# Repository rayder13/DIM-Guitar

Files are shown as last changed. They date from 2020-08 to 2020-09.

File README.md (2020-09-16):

# DIM-Guitar

## Introduction

(Did It Myself)DIM Guitar is a DIY full replacement for the oem electronics in a Warriors of Rock Playstation/Xbox Guitar Hero guitar. The result is a wired Clone Hero compatible guitar (Not console compatible), allowing you to either refurbish an existing guitar (WoR only atm) or create your own guitar from scratch. I will possibly be adding custom Fret key files, other 3d printable mounting options (For control board etc) and maybe new body variations that work with the original WoR (Warriors of Rock) body.

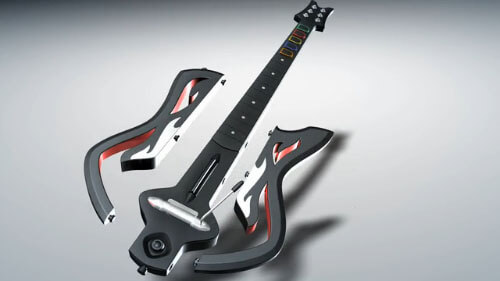
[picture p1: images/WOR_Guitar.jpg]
Image of WoR Guitar


## Progress

Electronics [Progress](PROGRESS.md) to keep up to date on how the project is going.

3D Print file [Progress](PRINTED.md).

Quick and dirty [Update Log](UPDATES.md).

## License

While I will be selling component kits and complete ready to install kits, the entire project is being released under GPL 3.0. Please read the license if you have any questions as to what you can and can't do.

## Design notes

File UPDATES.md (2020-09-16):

# Update Log

## 16/09/20

- Initial commit for 3D print files. WoR Fret Button added.

## 15/09/20

- Initial Arduino code commit to github.

## 16/08/20

- All pcb headers updated to carry 5v for future upgrades (led's etc).
- Update log added.
- Updated github files to 0.2.

## 11/08/20

- Initial commit of version 0.1.

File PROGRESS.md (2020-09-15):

# Progress

## Pinout

Below is the proposed pinout for the DIM Guitar based on an Arduino Pro Micro. The board should have enough GPIO's to accommodate the project. Hoping to use the TX/RX pins for future features but we will see how that pans out. Pin 7 is designated Fret 6 for future proofing a fork into GH6 6 fret guitar retro fit.

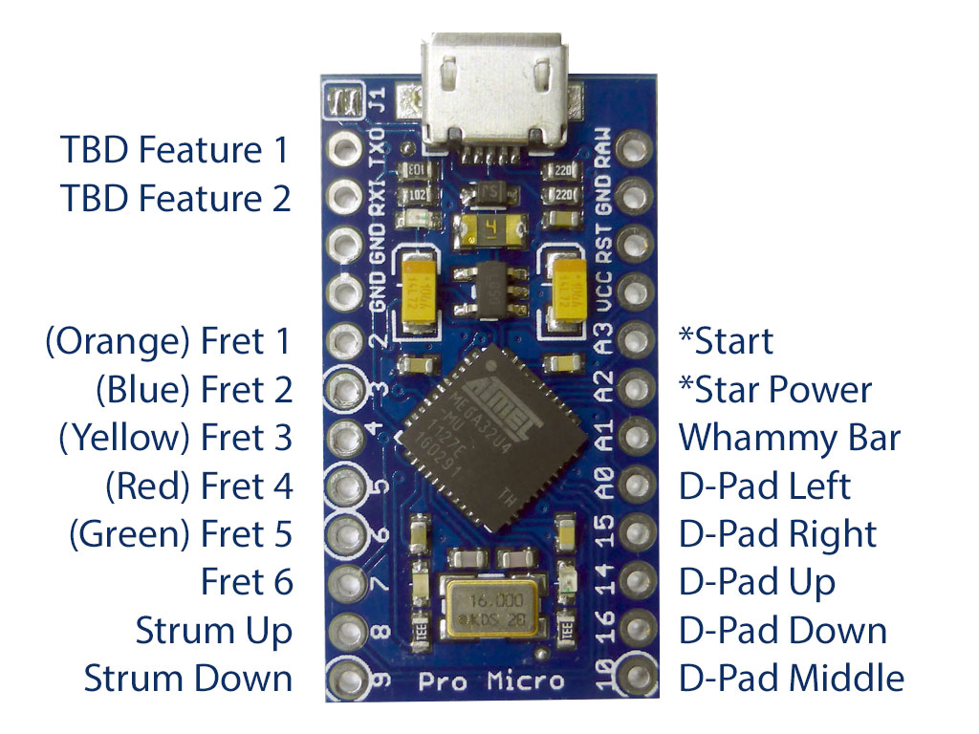
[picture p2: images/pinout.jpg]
Image of Pro Micro Pinout


## Working Prototype

Working prototype with D-Pad and Fretboard hooked up.

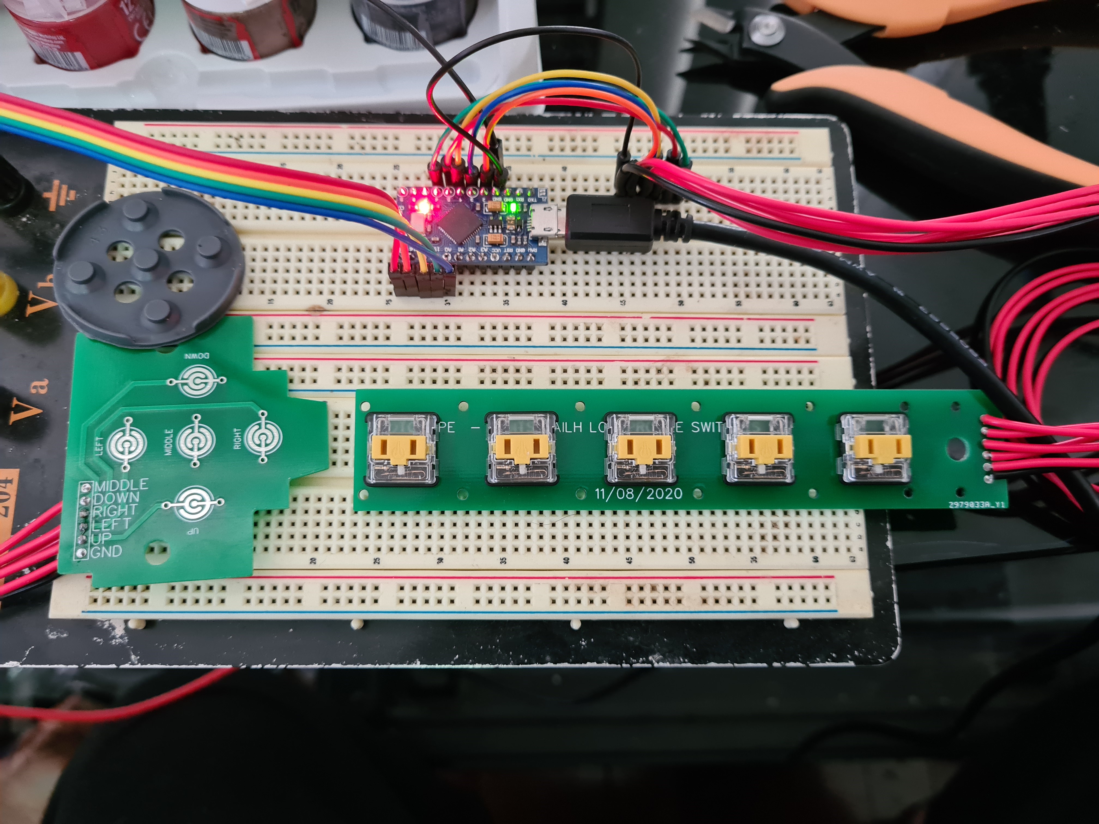
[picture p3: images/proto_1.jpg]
Image of current prototype


## Fretboard

- **September 15th 2020** Kailh switches arived today. Had to order a second lot directly from Kailh as the switches I originally ordered nearly 8 weeks ago from a reseller still haven't arrived. Turns out my pcb footprint for the switches is flipped horizontally. Not a huge deal as i can just flip the pcb given the only components are switches and the pcb is symmetrical vertically. Plus there are additions to come for the pcb so as long as i have a working prototype i can still progress.
- The switches appear to be too tall even though they are pretty much the shortest i could find. There isn't enough room below the pcb to mount them in the pcb so the fret buttons will have to be modified to get the extra internal travel needed.

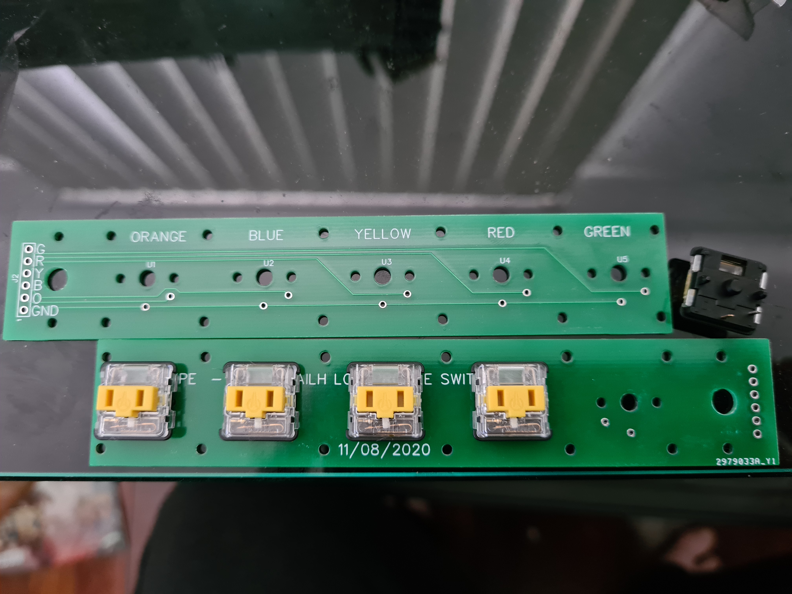
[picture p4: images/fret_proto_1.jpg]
Image of Prototype fretboard pcb


- **August 20th 2020** PCB's arrived 4 days early. Happy with these as far as quality and accuracy goes.

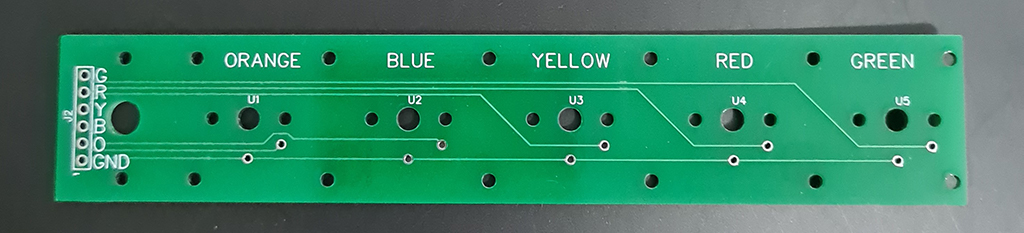
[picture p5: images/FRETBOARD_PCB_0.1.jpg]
Image of Prototype fretboard pcb


- Prototype pcb done and ordered. The pcb will use Kailh Choc low profile switches instead of the oem rubber membrane keys. This should fix sloppy fret keys and allow for a better feel depending on your preferences with tactile, clicky and linear keys available in the low profile switches.
- Potential to add led's to each switch for either all on lighting while connected or having the fret light up when pressed.

## D-Pad

- **August 20th 2020** PCB's arrived 4 days early.
- Works way better than expected, though research says that the exposed copper contacts will likely corrode over time and become unreliable. Will have to look into carbon or ENIG as a better option. For now the prototype 100% works as expected with no problems.

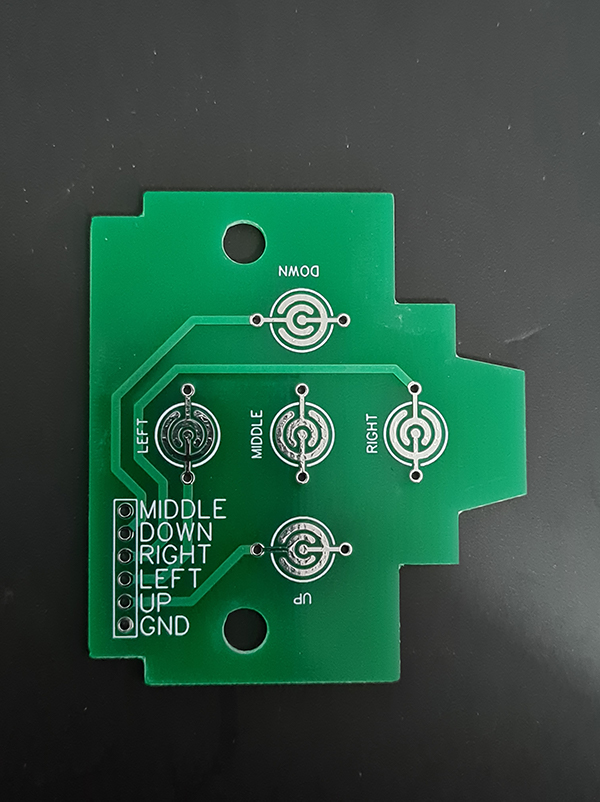
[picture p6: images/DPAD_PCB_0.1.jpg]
Image of Prototype dpad pcb


- Prototype pcb done and ordered. Utilising the original rubber membrane pad given how little the keys get used.
- Swapping to mechanical keys might not be easy given the confinement of space.

## Strummer

- **September 15th 2020** Kailh switches turned up. I ordered a set of Kailh box dark yellow switches to test for the strummer. They have a cherry footprint but a much thicker stem than normal Cherry switches which i like. Using the same footprint however gives you the ability to chop and change between switches as desired. They are however around 1-2mm shorter than the OEM switches. Might need a hat to make sure the strum bar doesn't feel "loose".

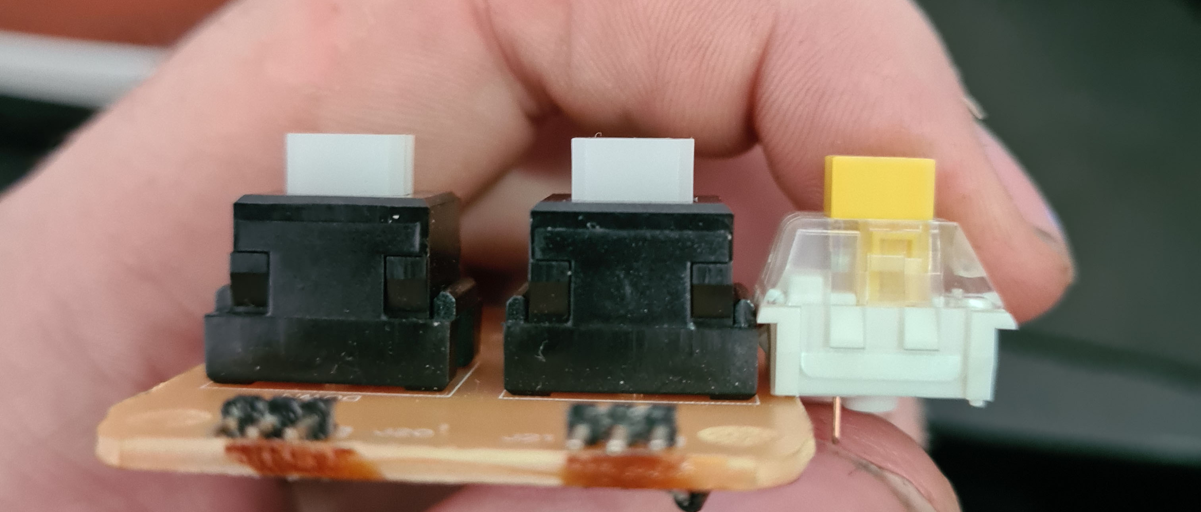
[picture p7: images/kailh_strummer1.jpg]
Image of Kailh box switch compared to OEM


- Prototype pcb in progress. Cherry MX Black version design done but i am waiting for the Kailh Chic low profile switches to show up to decide whether to use them, MX Cherry blacks or Alps keys.

Image of Prototype Strummer pcb

## Start/Star Power/Whammy

- Prototype pcb in progress. Will likely use Kailh Choc low profile switches as well.

Image of Prototype Mid Board pcb

## Arduino Controller

- Full working prototype was made on an Arduino Leonardo board. ~~Custom board based on the ATMEGA34U2 mcu will be prototyped after all of the other pcb's are verified working as intended.~~ A full pin hookup guild will be added on full release for anyone who wants to use an existing ATMEGA34U2 board (Arduino pro micro etc) as main controller board.
- After a bit of consideration the controller board will be a carrier board for an Arduino Pro Micro footprint instead of a custom 34U2 board. This will keep the costs down and realistically for this project there's no point reinventing the wheel.

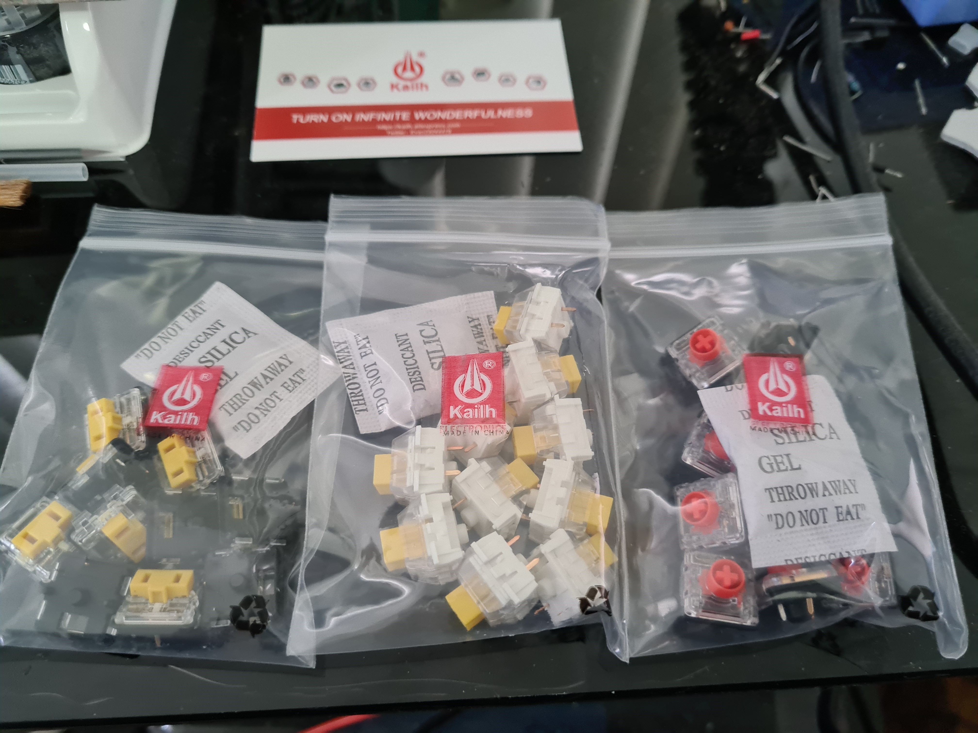
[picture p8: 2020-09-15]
images/switches.jpg

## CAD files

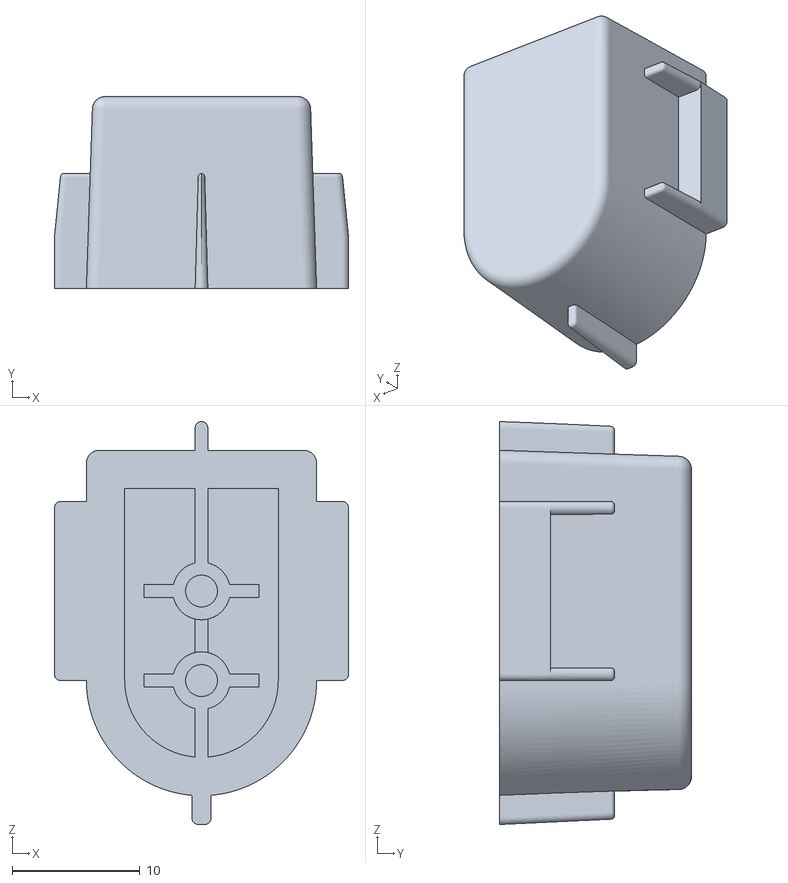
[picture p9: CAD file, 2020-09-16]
hardware/3D Print Files/WOR_Fret_Button.stl
23.0 x 15.0 x 31.5

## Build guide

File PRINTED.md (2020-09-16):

# 3D Print Files

## Fret Buttons

This is my first prototype for fret buttons to suit the WoR guitar fretboard. The initial print is pretty close to the original, or at least as close as i'm going to get with an FDM printer. Testing with the low profile Kailh switches says the fret buttons need an extra 5mm or so clearance so a modified fret button file will have to be made to accommodate that. But for now I mostly needed a confirmation of fit so that people can print them for themselves if they want.

All available STL's are in the [3D Print Files folder](hardware/3D%20Print%20Files/)

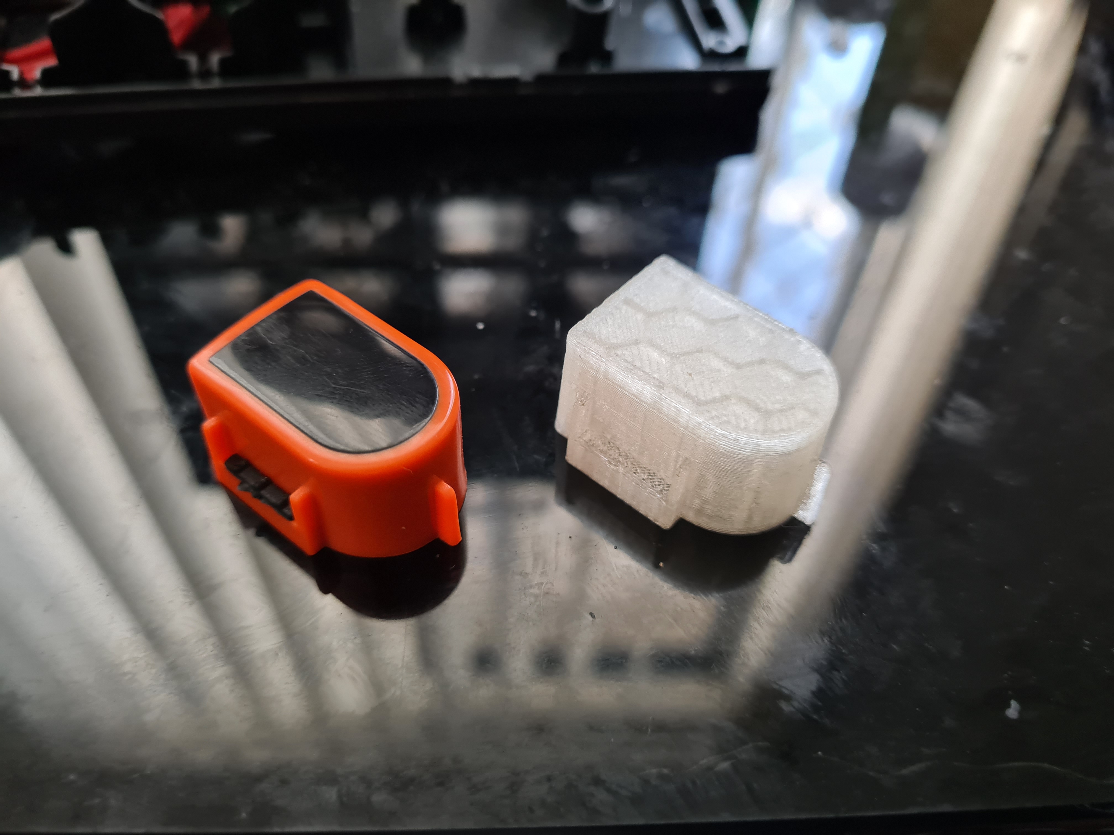
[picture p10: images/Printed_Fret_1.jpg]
Image of 3d printed fret proto


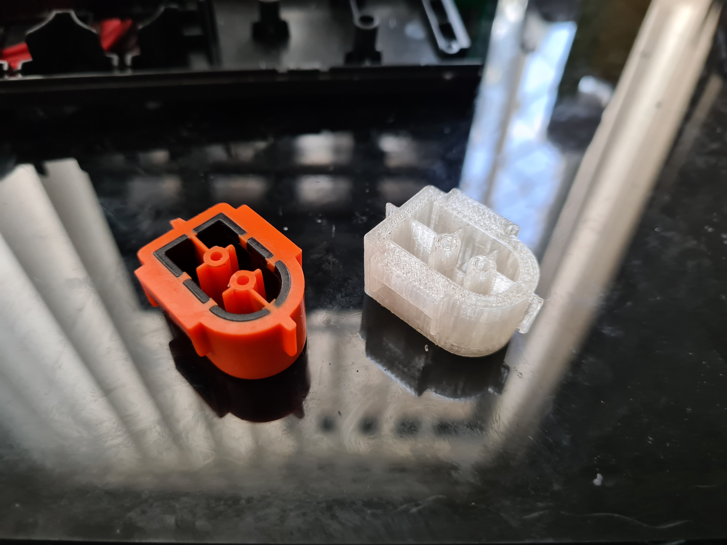
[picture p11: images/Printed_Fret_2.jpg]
Image of 3d printed fret proto


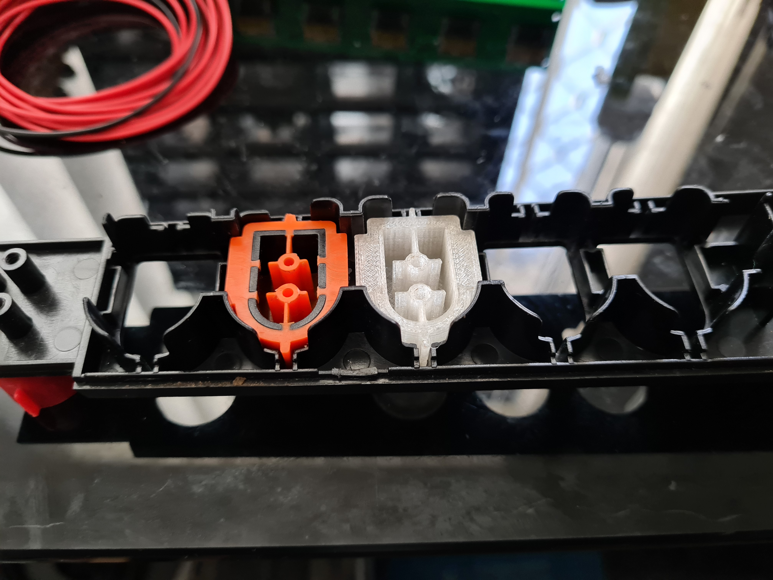
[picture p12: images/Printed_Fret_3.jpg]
Image of 3d printed fret proto


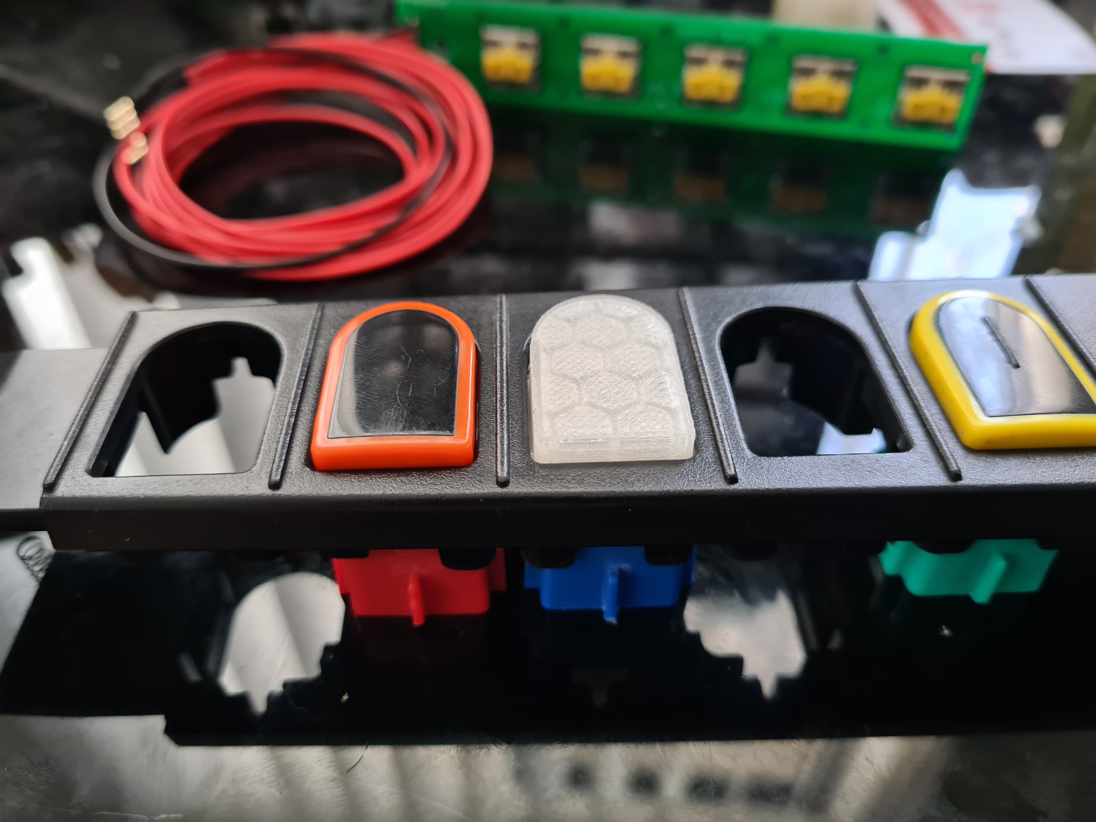
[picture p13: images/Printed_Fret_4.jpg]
Image of 3d printed fret proto


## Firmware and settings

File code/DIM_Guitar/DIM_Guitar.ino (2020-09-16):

// DIM-Guitar v0.2
// https://github.com/rayder13/DIM-Guitar
// Distributed under GPL 3.0 license.
// 
// NOTE: This sketch file is for use with Arduino Leonardo and
//       Arduino Micro only.
// 
// I have tried to retain as much of the original GH guitar
// functionality as possible while constraining everything
// to work on a 5v Pro Micro board.
//
// Uses the unmodified Joystick.h library from
// https://github.com/MHeironimus/ArduinoJoystickLibrary
// under GPL 3.0 license.
// 
// by rayder13
// 
//--------------------------------------------------------------------

#include <Joystick.h>

const int maxButtons = 15;

Joystick_ Joystick(JOYSTICK_DEFAULT_REPORT_ID,JOYSTICK_TYPE_GAMEPAD,
  maxButtons, 0,                 // 6 Fret Buttons, 5 D-Pad Buttons and 2 for up/down strum bar, start and star power, No Hat Switch
  true, false, false,    // X Axis for whammy bar, no Y Z Axis
  false, false, false,   // No Rx, Ry, or Rz
  false, false,          // No rudder or throttle
  false, false, false);  // No accelerator, brake, or steering

const byte buttonPin[] = {2, 3, 4, 5, 6, 7, 8, 9, 10, 14, 15, 16, A0, A2, A3};

void setup() {

//  Serial.begin(9600);
//  while (!Serial) {
//    delay(200); // wait for serial port to connect. Needed for native USB
//  }
  
  // Initialize Button Pins
  pinMode(2, INPUT_PULLUP);   // Fret 1
  pinMode(3, INPUT_PULLUP);   // Fret 2
  pinMode(4, INPUT_PULLUP);   // Fret 3
  pinMode(5, INPUT_PULLUP);   // Fret 4
  pinMode(6, INPUT_PULLUP);   // Fret 5
  pinMode(7, INPUT_PULLUP);   // Fret 6
  pinMode(8, INPUT_PULLUP);   // Strum Up
  pinMode(9, INPUT_PULLUP);   // Strum Down
  pinMode(10, INPUT_PULLUP);  // D-Pad Middle
  pinMode(14, INPUT_PULLUP);  // D-Pad Up
  pinMode(15, INPUT_PULLUP);  // D-Pad Right
  pinMode(16, INPUT_PULLUP);  // D-Pad Down
  pinMode(A0, INPUT_PULLUP);  // D-Pad Left
  pinMode(A1, INPUT);         // Whammy Bar
  pinMode(A2, INPUT_PULLUP);  // Star Power
  pinMode(A3, INPUT_PULLUP);  // Start

  // Initialize Joystick Library
  Joystick.begin();

  // The original potentiometer in the WoR guitar doesn't have full range of
  // motion (0-1023). Seems to go up to around 650 so set to 600 to ensure
  // effects of existing wear is minimised.
  Joystick.setXAxisRange(1, 600); 
}

// Constant that maps the phyical pin to the joystick button.
// 15/09/20 probably have no use for this?
// const int pinToButtonMap = 2;

// Last state of the buttons
int lastButtonState[maxButtons] = {0,0,0,0,0,0,0,0,0,0,0,0,0,0,0};

void loop() {

  // Read pin values
  for (int index = 0; index < maxButtons; index++)
  {
//    int currentButtonState = !digitalRead(index + pinToButtonMap);
    int currentButtonState = !digitalRead(buttonPin[index]);
    if (currentButtonState != lastButtonState[index])
    {
      Joystick.setButton(index, currentButtonState);
      lastButtonState[index] = currentButtonState;
    }
    
    int whammyPos = analogRead(A1);
    Joystick.setXAxis(whammyPos);
//    Serial.println(analogRead(A1));
  }

  delay(10);
}

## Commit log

2020-08-12 Prototype Easyeda Gerbers
2020-08-12 PCB Image uploads
2020-08-12 Proto Gerbers
2020-08-12 Dead pcb image removal
2020-08-12 schematic images
2020-08-20 First pcb prototype imahes
2020-08-20 readme updated with pcb images
2020-09-15 kailh switches arrived
2020-09-16 initial commit of 3d print files
    [WOR_Fret_Button.stl]
2020-09-16 3d printed fret images
